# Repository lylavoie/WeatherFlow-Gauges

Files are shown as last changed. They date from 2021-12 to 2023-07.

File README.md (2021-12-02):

# WeatherFlow-Gauges

Drive a set of analog gauges from the UDP broadcast reports from a WeatherFlow Tempest weather station, using an ESP32 microcontroller.  Current gauges are for Wind Speed (MPH), Wind Direction (cardinal heading), and Temperature (degrees F).  The wind direction assumes there will be 8 LEDs, driven from an SPI output register.

The design is based the [TinyPICO](https://www.tinypico.com/) board.
Analog outputs are created from PWM output, combined with a low pass
filter.  Eight LEDs are driven from through an MCP23008 GPIO chip.  Two
additional LED (or general purpose digital outputs) are also provided
by GPIO pins on the TinyPICO. along with two digial inputs (buttons).

Power connections are J1, providing 5 to 12 volts DC, or through the
USB connection on the TinyPICO.

## PCB Design

The ``pcb/pdf`` directory provides the schematics and design layout of
the board.  The ``pcb/gerbers`` directory contains the production files
to spin the PCB board.

## Firmware

The firmware (this repo) is built via [PlatformIO](https://platformio.org/)
and VS Code.  Programming can be via the USB interfaces over over
the air, by selecting the built enviroment *tinypico_ota*.

## Operation & Setup

Settings are stored persistenly in the ESP32 EEPROM.  If the system
does not have a valid configuration, it will enable AP mode,
broadcasting the open (no encryption or passkey) SSID
*WeatherFlowGauges*.  After connecting to the system, the system
can be configured through a web broswer via
[http://192.168.4.1](http://192.168.4.1).  The initial username and
password is *admin*/*temp*.

System status is provided through the RBG LED on the TinyPICO board.

| LED Color | Meaning
| --- | ---
| Solid Blue | Trying to connect to Wi-Fi
| Pulsing Green | System connected to Wi-Fi, normal operation
| Color Wheel Cycle | Running as Wi-Fi AP, waiting for setup
| Solid Orange | Factory reset started
| Solid Red | Factory reset completed

### Factory Reset

While holding down **Button 1**, press the **Reset** button.  The
RBD LED will turn orange, keep holding Button 1 for at least 5
seconds until the RGB LED turns red, then release. The system has
now been reset back to the factory default settings.

## Gauages

TBD

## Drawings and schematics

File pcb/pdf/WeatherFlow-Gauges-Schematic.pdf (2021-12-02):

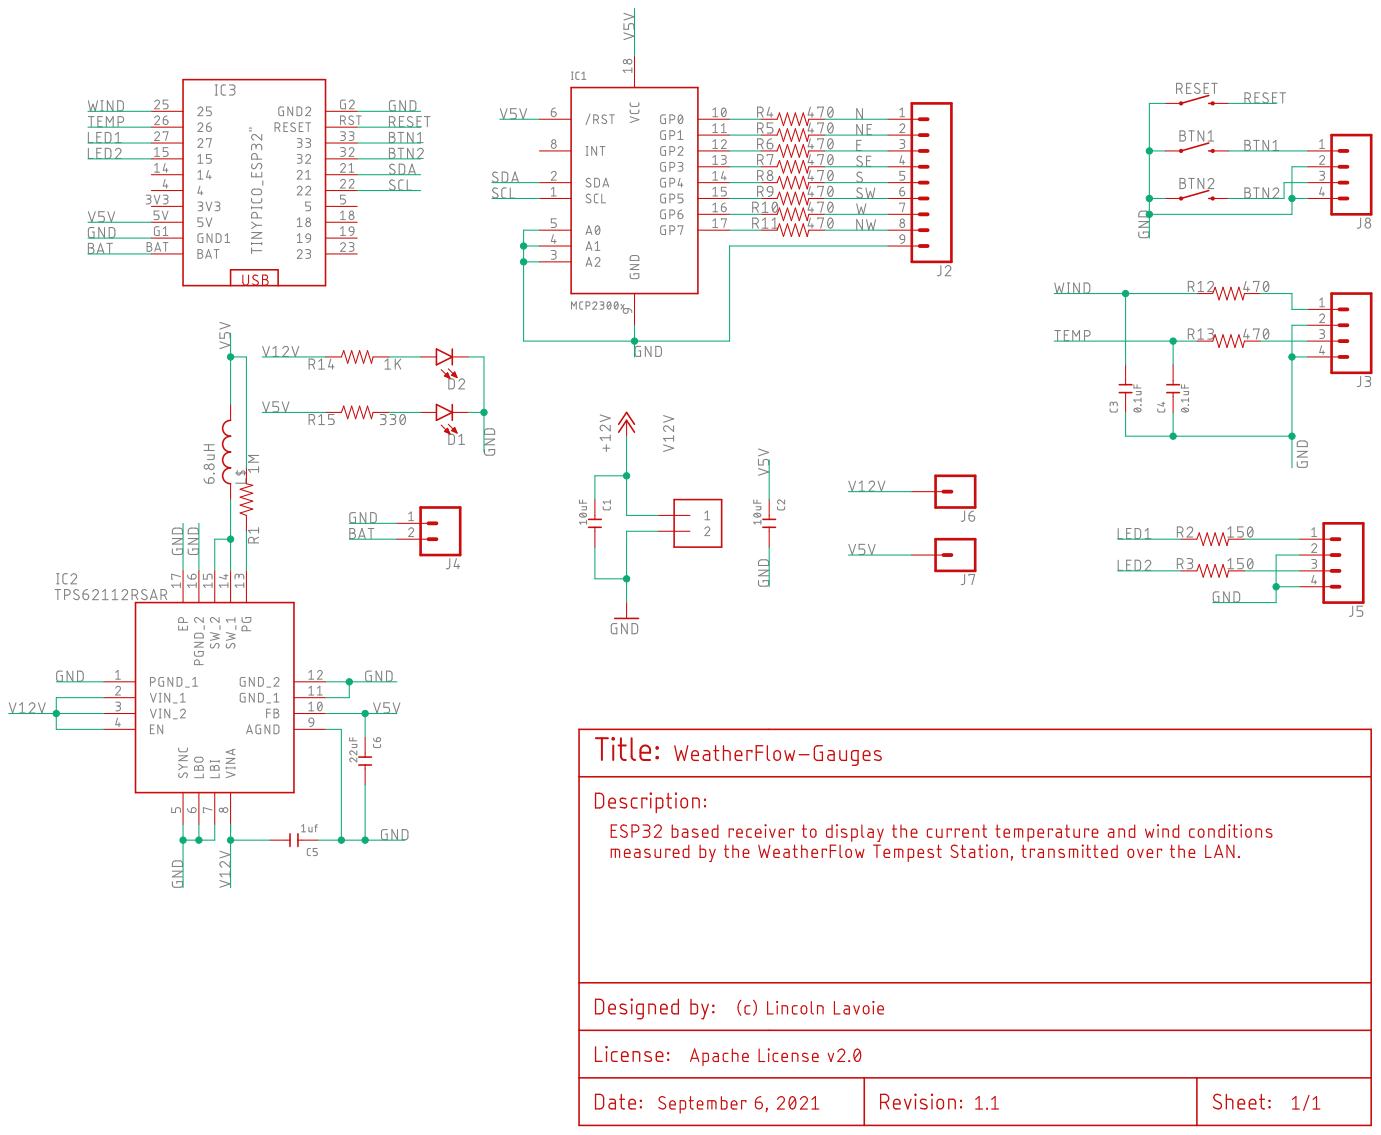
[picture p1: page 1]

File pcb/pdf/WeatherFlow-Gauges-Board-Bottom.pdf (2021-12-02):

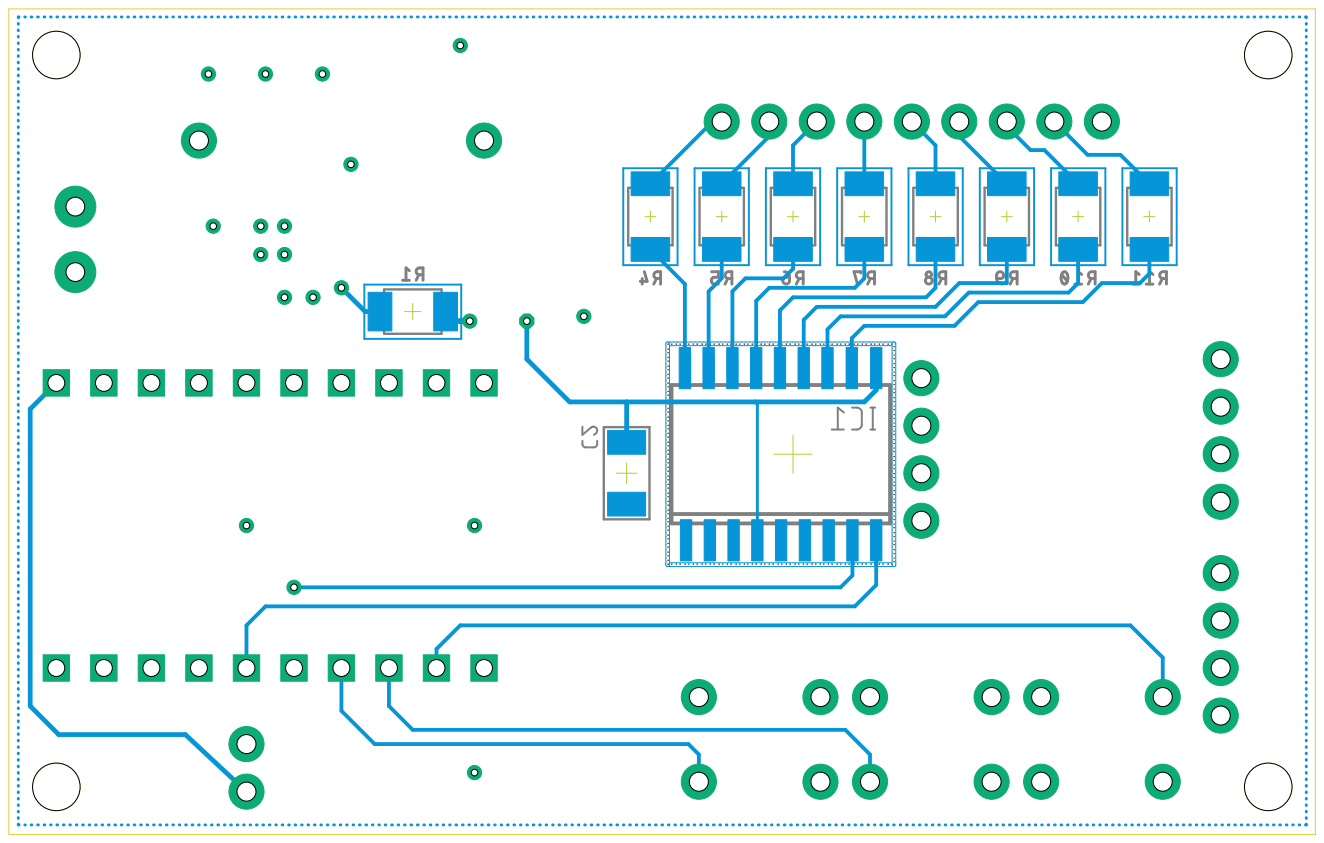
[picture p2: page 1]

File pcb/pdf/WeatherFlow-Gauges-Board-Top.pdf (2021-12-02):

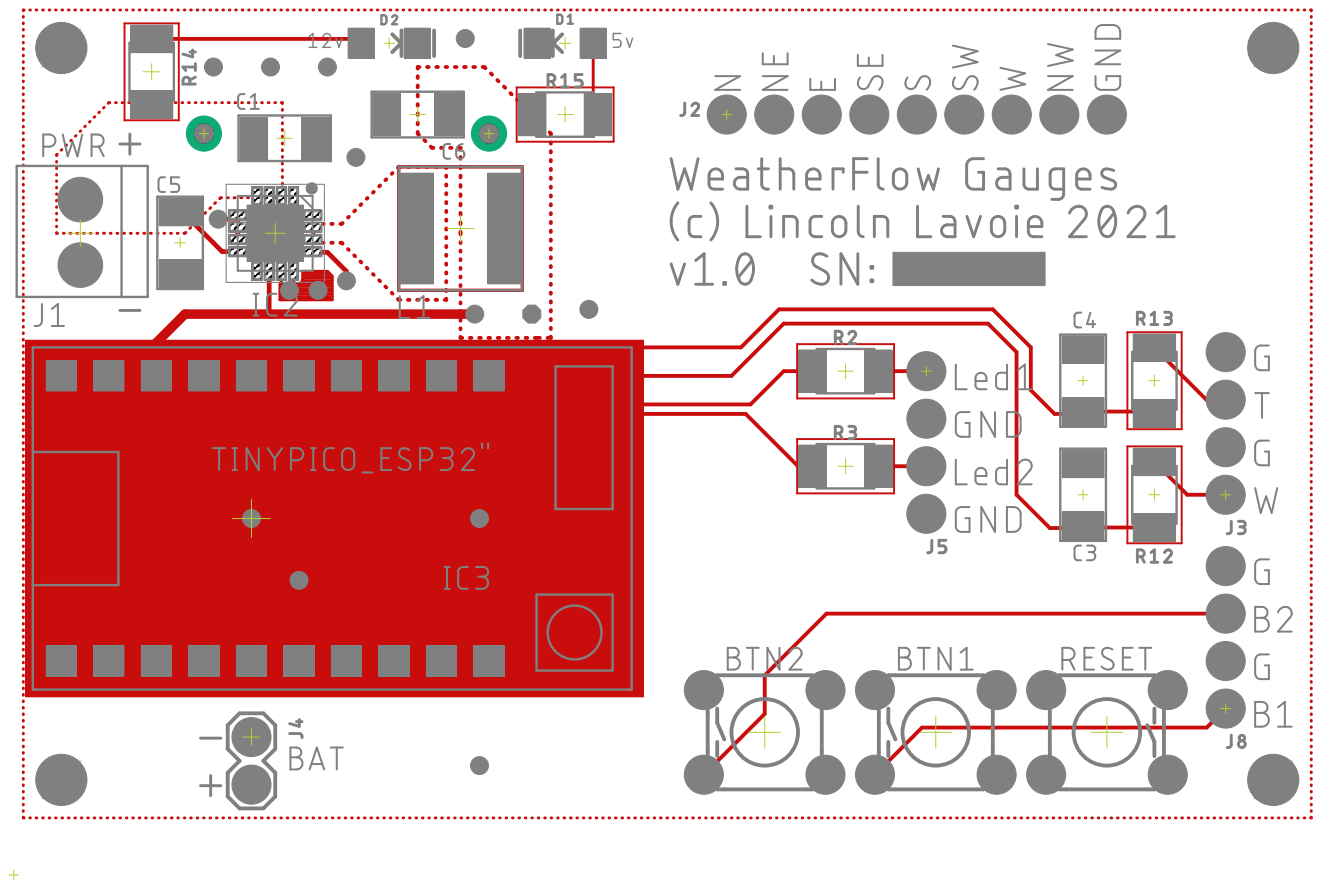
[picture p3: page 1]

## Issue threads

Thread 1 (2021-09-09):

Recover MCP23008 chip after resume from battery

lylavoie, 2021-09-09:
The MCP23008 chip is powered from the 5V supply, and when the TinyPICO power is restored, the chip needs to be reset / reinitialized.

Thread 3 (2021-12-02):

Power GPIO chip from 3V source

lylavoie, 2021-12-02:
Change PCB design to power the MCP23008 chip from the 3 volt source, which will allow it to run from the battery backup.

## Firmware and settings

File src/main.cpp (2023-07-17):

#include <Arduino.h>
#include <WiFi.h>
#include <AsyncTCP.h>
#include <ESPAsyncWebServer.h>
#include <ESPmDNS.h>
#include <ArduinoJson.h>
#include <TinyPICO.h>
#include <Adafruit_MCP23X08.h>
#include <SPIFFS.h>
#include <esp_task_wdt.h>
#include <wf.h>
#include <PersistSettings.h>
#include "Config.h"
#include <map>
#include <ctime>
#include <math.h>

// Note, these are required because of https://community.platformio.org/t/identifier-is-undefined-setenv-tzset/16162/2
//_VOID  _EXFUN(tzset,	(_VOID));
//int	_EXFUN(setenv,(const char *__string, const char *__value, int __overwrite));

// Version info
#define MAJOR 1
#define MINOR 3
#define PATCH 0

// Debug Info
#define DEBUG 2
void debug(int level, const char *fmt, ...);

// Hardware board
TinyPICO TP = TinyPICO();
// Output Guages
#define WINDGAUGEPIN 25
#define WINDCHANNEL 0
#define TEMPGAUGEPIN 26
#define TEMPCHANNEL 1
// Input/Output Settings
#define BTNPIN1 33
#define BTNPIN2 32
#define LED1 27
#define LED1CHANNEL 2
#define LED2 15
#define LED2CHANNEL 3

// WeatherFlow Handler
WeatherFlow WF(Imperial);

// Persistent Settings Handler
PersistSettings<AppConfig> Settings(AppConfig::Version);

// Hardware I2C GPIO extender
Adafruit_MCP23X08 mcp;

// Function Prototypes
void ledcAnalogWrite(uint8_t channel, uint32_t value, uint32_t valueMax = 8191);
uint32_t scalePwmOutput(double dataVal, double minScale, double maxScale, double halfScalePWM = 3600);
uint8_t encodeWind(int windDir);
void RunCalibration(void);


// WiFi Parameters
bool bSoftApActive = false;
#define AP_MODE_SSID "WeatherFlowGauges"

// Webserver and Websockets
AsyncWebServer objWebServer(80);
AsyncWebSocket objWebSocket("/ws");
void onWebSocketEvent(AsyncWebSocket *server, AsyncWebSocketClient *client, AwsEventType type,
  void *arg, uint8_t *data, size_t len);
void handleWebSocketMessage(AwsFrameInfo *info, uint8_t *data, size_t len);
String webTemplateProcessor(const String& var);
void webServerSpiffsHandler(AsyncWebServerRequest *request);

enum CalMode { none, range };
CalMode CalibrationMode = none;


// ##################################################################
// # Setup
// ##################################################################

void setup() {

  // ==================================================
  // Hardware Init Stuff
  // ==================================================
  SPIFFS.begin();

  // ==================================================
  // Setup the serial port for logging, if debugging
  // ==================================================
  #ifdef DEBUG
  Serial.begin(9600);
  while(!Serial)
  {
    Serial.print('.');
  }
  #endif
  
  // ==================================================
  // Settings (non-volitale)
  // ==================================================
  Settings.Begin();

  // ==================================================
  // Button Setup & Reset Default Settings
  // ==================================================
  pinMode(BTNPIN1, INPUT_PULLUP);
  int iSwitchDebounce = 0;
  while( !digitalRead(BTNPIN1) ){
    // Stage 0 reset, debouncing for 5 seconds
    TP.DotStar_SetPixelColor(0xFF9A00);
    TP.DotStar_SetBrightness(150);
    TP.DotStar_SetPower(true);
    // Stage 1 reset
    if( iSwitchDebounce++ > 10 ){
      TP.DotStar_SetPixelColor(0xFF0000);
      Settings.ResetToDefault();
      delay(5000);
      ESP.restart();
    }
    delay(500);
  }

  // ==================================================
  // Environment Startup
  // ==================================================
  setenv("TZ", Settings.Config.TimeZone, true);
  tzset();

  // ==================================================
  // Wi-Fi Startup
  // ==================================================
  if( !Settings.Config.WiFi.ssid[0] || !Settings.Config.WiFi.pass[0] ){
    // ------------------------------------
    // Soft AP mode
    // ------------------------------------
    debug(1, "\n\rWi-Fi parameters not set, starting AP mode.");
    
    // Start the AP mode
    debug(1, "\n\rStarting Wi-Fi AP for SSID: WeatherFlow");
    if( !WiFi.softAP(AP_MODE_SSID) ){
      debug(1, "\n\rFailed to start AP mode!");
      while(1);
    }

    bSoftApActive = true;
    TP.DotStar_SetBrightness(150); 
  }
  else{
    // ------------------------------------
    // STA mode
    // ------------------------------------
    debug(1, "\n\rConecting to Wi-Fi: %s ...", Settings.Config.WiFi.ssid);
    WiFi.begin(Settings.Config.WiFi.ssid, Settings.Config.WiFi.pass);
    int iWiFiFailCount = 0;
    TP.DotStar_SetPixelColor(0x0000FF);
    while(WiFi.status() != WL_CONNECTED)
    {
      debug(1, ".");
      delay(500);
      // Five some feedback via the DotStar
      if( iWiFiFailCount++ % 2 ){TP.DotStar_SetBrightness(150);}
      else{TP.DotStar_SetBrightness(25);}
      
    }

    debug(1, "\n\rWi-Fi connected!");
    TP.DotStar_SetPixelColor(0x00FF00);
    TP.DotStar_SetBrightness(25);
    #ifdef DEBUG
    char  chIP[81];
    WiFi.localIP().toString().toCharArray(chIP, sizeof(chIP) - 1);
    debug(1, "\n\rIP Address: %s", chIP);
    #endif
  }

  // ==================================================
  // IP Services
  // ==================================================

  // Setup mDNS
  if ( !MDNS.begin("wxgauges") ){debug(1, "Failed to start mDNS responder!");}

  // Setup the webserver and websocket handling
  // FIXME: Handle firmware update
  //objWebServer.on("/update", HTTP_POST, NULL);
  objWebServer.on("/logout", HTTP_GET, [](AsyncWebServerRequest *request){request->send(401);});
  objWebServer.on("/logged-out.html", HTTP_GET, webServerSpiffsHandler);
  objWebServer.onNotFound([](AsyncWebServerRequest *request){
    if( !request->authenticate(Settings.Config.Web.user, Settings.Config.Web.pass) )
      return request->requestAuthentication();
    webServerSpiffsHandler(request);
  });
  objWebSocket.onEvent(onWebSocketEvent);
  objWebServer.addHandler(&objWebSocket);
  objWebServer.begin();


  // ==================================================
  // PWM controls for gauge outputs
  // ==================================================
  
  // Wind PWM freq 5 kHz, 13-bit timer resolution
  ledcSetup(WINDCHANNEL, 5000, 13);
  ledcAttachPin(WINDGAUGEPIN, WINDCHANNEL);

  // Temp PWM freq 5 kHz, 13-bit timer resolution
  ledcSetup(TEMPCHANNEL, 5000, 13);
  ledcAttachPin(TEMPGAUGEPIN, TEMPCHANNEL);

  // LED PWM Setup, 5 kHz, 13-bit timer
  ledcSetup(LED1CHANNEL, 5000, 13);
  ledcAttachPin(LED1, LED1CHANNEL);
  ledcAnalogWrite(LED1CHANNEL, 0);
  ledcSetup(LED2CHANNEL, 5000, 13);
  ledcAttachPin(LED2, LED2CHANNEL);
  ledcAnalogWrite(LED2CHANNEL, 0);

  // ==================================================
  // Setup MCP23008 I2C GPIO Expander
  // ==================================================
  if (!mcp.begin_I2C()) {debug(1, "\n\rFailed to startup MCP23008!");}
  for(int i=0; i<8; i++)mcp.pinMode(i, OUTPUT);

  // ==================================================
  // Start listening for UDP messages
  // ==================================================
  if( !WF.Begin() )debug(1, "\n\rFailed to start WeatherFlow listener!");

  // ==================================================
  // Enable the watchdog timer
  // ==================================================
  esp_task_wdt_init(10, false);
  esp_task_wdt_add(NULL);
}

// ##################################################################
// # Main Loop
// ##################################################################

void loop() {
  static uint32_t u32WindPwm;
  static uint32_t u32TempPwm;
  static uint8_t u8WindDir;
  time_t ul32CurTime;
  static time_t ul32LastBlink;
  static bool bOneShot = false;
  static bool bGaugeLamp = false;


  // ================================================================
  // Watchdog timer reset & current time
  // ================================================================   
  time(&ul32CurTime);
  esp_task_wdt_reset();


  // ================================================================
  // Calibration modes
  // ================================================================
  if( CalibrationMode == range){
    debug(1, "\n\rRunning in calibration mode, current epoch time: %d", ul32CurTime);
    RunCalibration();
    delay(5000);
    return;
  }
  
  if( bSoftApActive ){
    // ================================================================
    // Wi-Fi in AP mode, allowing for user setup...
    // ================================================================
    // Cycle the DotStar color, just to give the user some feedback
    TP.DotStar_CycleColor(25);
  }
  else{
    // ================================================================
    // Wi-Fi in client mode, listening for WeatherFlow messages
    // ================================================================

    // Status via DotStar LED
    if( ul32CurTime%15 == 0 && !bOneShot ){
      bOneShot = true;
      TP.DotStar_SetPixelColor(0x00FF00);
      ul32LastBlink = ul32CurTime;
      // Log the current time
      char buf[128];
      strftime(buf, 128, "%c", localtime(&ul32CurTime));
      debug(1, "\n\rCurrent System Time: %s", buf); 
      debug(1, "\r\nFirmware Version: %d.%d.%d", MAJOR, MINOR, PATCH);
    }
    if( ul32CurTime - ul32LastBlink >= 1 ){
      bOneShot = false;
      TP.DotStar_SetPixelColor(0x0);
    }

    // ================================================================
    // WeatherFlow receiver loop function call, return indicates
    // new data is available
    // ================================================================
    if( WF.ReceiveLoop() ){
      debug(1, "\n\rReceived updated weather info...");
      
      // Check for Wind data
      if( WF.RapidWind().Valid() ){
        debug(1, "\n\rValid Rapid Wind data:");
        debug(1, "\n\r\tWind Speed: %f", WF.RapidWind().WindSpeed());
        debug(1, "\n\r\tWind Direction: %d", WF.RapidWind().WindDirection());

        u32WindPwm = scalePwmOutput(WF.RapidWind().WindSpeed(), Settings.Config.Wind.min,
          Settings.Config.Wind.max, Settings.Config.Wind.gain);
        debug(2, "\n\r\tWind PWM: %i", u32WindPwm);
        ledcAnalogWrite(WINDCHANNEL, u32WindPwm);

        if( WF.RapidWind().WindSpeed() >= Settings.Config.Wind.threshold ){ 
          u8WindDir = encodeWind(WF.RapidWind().WindDirection()); 
        }
        else{ 
          u8WindDir = 0x00;
        }
        debug(2, "\n\r\tWind direction code: 0x%02X", u8WindDir);
        mcp.writeGPIO(u8WindDir, 0);

        // Check if we need to update our system time
        if( abs(time(NULL) - WF.RapidWind().EpochTime()) > 10 ){
          debug(1, "\n\r\tUpdating the system time...");
          timeval WFtime;
          WFtime.tv_sec = WF.RapidWind().EpochTime();
          WFtime.tv_usec = 0;
          settimeofday(&WFtime, NULL);
          debug(2, "\n\r\t\tWF Epoch Time: %d", WF.RapidWind().EpochTime());
          debug(2, "\n\r\t\tSystem Time:   %d", time(NULL));
        }
      }

      // Check for valid Station data
      if( WF.ObservationTempest().Valid() ){
        debug(1, "\n\rValid Station Observation data:");
        debug(1, "\n\r\tAir Temperature: %f", WF.ObservationTempest().AirTemperature());
        u32TempPwm = scalePwmOutput(WF.ObservationTempest().AirTemperature(), Settings.Config.Temp.min,
          Settings.Config.Temp.max, Settings.Config.Temp.gain);
        debug(2, "\n\r\tTemp PWM: %i", u32TempPwm);
        ledcAnalogWrite(TEMPCHANNEL, u32TempPwm);
      }
    }
  
    // ================================================================
    // Check our current time, turn on the gauge lamps if needed
    // ================================================================
    tm *tmCurrentTime;
    tmCurrentTime = localtime(&ul32CurTime);
    if( !bGaugeLamp && tmCurrentTime->tm_hour == Settings.Config.GaugeLamps.OnHour 
        && tmCurrentTime->tm_min == Settings.Config.GaugeLamps.OnMinute ){
      bGaugeLamp = true;
      ledcAnalogWrite(LED1CHANNEL, scalePwmOutput(Settings.Config.GaugeLamps.LampBrightness, 0, 100, 4096));
    }
    if( bGaugeLamp && tmCurrentTime->tm_hour == Settings.Config.GaugeLamps.OffHour && 
        tmCurrentTime->tm_min == Settings.Config.GaugeLamps.OffMinute ){
      bGaugeLamp = false;
      ledcAnalogWrite(LED1CHANNEL, 0);
    }
  }

}

// ##################################################################
// # Debug printer
// #
// # Debug logging to the serial port, message is only printed if 
// # the level is >= to DEBUG (i.e. debugging level).  If DEBUG is
// # undefined, code is deactivated.
// ##################################################################
void debug(int level, const char *fmt, ...){
  #ifdef DEBUG
  if( level <= DEBUG ){
    char chBuffer[256];
    va_list args;
    va_start(args,fmt);
    vsprintf(chBuffer, fmt, args);
    va_end(args);
    Serial.print(chBuffer);
  }
  #endif
}

// ####################################################################
// # Run Calibration
// #
// # Runs a simple calibration, steping through the gauge "steps",
// # on each call (i.e. once per loop).  This allows the gain values
// # to easily be "tuned."
// ####################################################################
void RunCalibration(void){
  static float fWindSpeed = 0;
  static float fAirTemp = 0;
  static int iWindDirectionDegrees = 0;
  uint32_t u32WindPwm;
  uint32_t u32TempPwm;
  uint8_t u8WindDir;

  u32WindPwm = scalePwmOutput((double)fWindSpeed, Settings.Config.Wind.min, 
    Settings.Config.Wind.max, (double)Settings.Config.Wind.gain);
  debug(1, "\n\rWind PWM: %i", u32WindPwm);
  ledcAnalogWrite(WINDCHANNEL, u32WindPwm);

  fWindSpeed += Settings.Config.Wind.step;
  if( fWindSpeed > Settings.Config.Wind.max )fWindSpeed = Settings.Config.Wind.min;

  u32TempPwm = scalePwmOutput((double)fAirTemp, Settings.Config.Temp.min, 
    Settings.Config.Temp.max, (double)Settings.Config.Temp.gain);
  debug(1, "\n\rTemp PWM: %i", u32TempPwm);
  ledcAnalogWrite(TEMPCHANNEL, u32TempPwm);
  
  fAirTemp += Settings.Config.Temp.step;
  if( fAirTemp > Settings.Config.Temp.max )fAirTemp = Settings.Config.Temp.min;

  iWindDirectionDegrees+= 15;
  if( iWindDirectionDegrees > 360 )iWindDirectionDegrees = 0;
  u8WindDir = encodeWind(iWindDirectionDegrees);
  debug(1, "\n\rWind direction code: 0x%02X", u8WindDir);
  mcp.writeGPIO(u8WindDir, 0);
}


// ##################################################################
// # PWM and Wind LED outputs
// ##################################################################

// Analog PMW control, similar to Arduino analogWrite
void ledcAnalogWrite(uint8_t channel, uint32_t value, uint32_t valueMax) {
  // Write duty to LEDC, preventing writing above the max value
  ledcWrite(channel, min(value, valueMax));
}

// Scale our guage values, as needed
uint32_t scalePwmOutput(double dataVal, double minScale, double maxScale, double halfScalePWM){
  //double dRange = maxScale - minScale;
  //double dScaler = 1 / dRange;
  uint32_t u32Output = (uint32_t)floor(((dataVal - minScale) * halfScalePWM * (double)2) / (maxScale - minScale));
  return min(u32Output, (uint32_t)8192);
}

// Encode wind direction to the output for the LED driver.
// Assumes 8 LEDs, connected to 8-bit register
uint8_t encodeWind(int windDir){
  uint8_t u8WindDir;

  if( windDir >= (int)348.75 || windDir < (int)11.25 ){ u8WindDir = 0x01; debug(3,"\n\rWind Dir: N"); }         // N
  else if( windDir >= (int)11.25 && windDir < (int)33.75 ){ u8WindDir = 0x03; debug(3,"\n\rWind Dir: NNE"); }   // NNE
  else if( windDir >= (int)33.75 && windDir < (int)56.25 ){ u8WindDir = 0x02; debug(3,"\n\rWind Dir: NE"); }    // NE
  else if( windDir >= (int)56.25 && windDir < (int)78.75 ){ u8WindDir = 0x06; debug(3,"\n\rWind Dir: ENE"); }   // ENE
  else if( windDir >= (int)78.75 && windDir < (int)101.25 ){ u8WindDir = 0x04; debug(3,"\n\rWind Dir: E"); }    // E
  else if( windDir >= (int)101.25 && windDir < (int)123.75 ){ u8WindDir = 0x0C; debug(3,"\n\rWind Dir: ESE"); } // ESE
  else if( windDir >= (int)123.75 && windDir < (int)146.25 ){ u8WindDir = 0x08; debug(3,"\n\rWind Dir: SE"); }  // SE
  else if( windDir >= (int)146.25 && windDir < (int)168.75 ){ u8WindDir = 0x18; debug(3,"\n\rWind Dir: SSE"); } // SSE
  else if( windDir >= (int)168.75 && windDir < (int)191.25 ){ u8WindDir = 0x10; debug(3,"\n\rWind Dir: S"); }   // S
  else if( windDir >= (int)191.25 && windDir < (int)213.75 ){ u8WindDir = 0x30; debug(3,"\n\rWind Dir: SSW"); } // SSW
  else if( windDir >= (int)213.75 && windDir < (int)236.25 ){ u8WindDir = 0x20; debug(3,"\n\rWind Dir: SW"); }  // SW
  else if( windDir >= (int)236.25 && windDir < (int)258.75 ){ u8WindDir = 0x60; debug(3,"\n\rWind Dir: WSW"); } // WSW
  else if( windDir >= (int)258.75 && windDir < (int)281.25 ){ u8WindDir = 0x40; debug(3,"\n\rWind Dir: W"); }   // W
  else if( windDir >= (int)281.25 && windDir < (int)303.75 ){ u8WindDir = 0xC0; debug(3,"\n\rWind Dir: WNW"); } // WNW
  else if( windDir >= (int)303.75 && windDir < (int)326.25 ){ u8WindDir = 0x80; debug(3,"\n\rWind Dir: NW"); }  // NW
  else{ u8WindDir = 0x81; debug(3,"\n\rWind Dir: NNW"); }                                                       // NNW

  return u8WindDir;
}

// ##################################################################
// # Web Services (http server and websockets)
// ##################################################################

void notFound(AsyncWebServerRequest *request){
    request->send(404, "text/plain", "Not found");
}

void webServerSpiffsHandler(AsyncWebServerRequest *request){
  String path = request->url();
  String contentType;
  debug(2, "handleFileRead: %s", path);
  if (path.endsWith("/")) path += "index.html"; // Deal with the roots
  if (path.endsWith(".html")) contentType = "text/html";
  else if (path.endsWith(".css")) contentType = "text/css";
  else if (path.endsWith(".js")) contentType = "application/javascript";
  else if (path.endsWith(".ico")) contentType = "image/x-icon";
  else contentType = "text/plain";
  if( SPIFFS.exists(path) ){ 
    request->send(SPIFFS, path, contentType, false, webTemplateProcessor); 
  }
  else{ 
    request->send(404, "text/plain", "Not Found");
  }
}

void onWebSocketEvent(AsyncWebSocket *server, AsyncWebSocketClient *client, AwsEventType type,
    void *arg, uint8_t *data, size_t len){
  switch (type) {
  #ifdef DEBUG
    case WS_EVT_CONNECT:
      debug(1, "\r\nWebsocket connected (ClientID: %u, ClientIP:  %s)", client->id(), client->remoteIP().toString());
      break;
    case WS_EVT_DISCONNECT:
      debug(1, "\r\nWebscoked disconnected (ClientID: %u", client->id());
      break;
    case WS_EVT_PONG:
    case WS_EVT_ERROR:
      break;
  #endif
    case WS_EVT_DATA:
      handleWebSocketMessage( (AwsFrameInfo*) arg, data, len);
      break;
  }    
  return;
  }

void handleWebSocketMessage(AwsFrameInfo *info, uint8_t *data, size_t len){
  // Make sure this is a complete message and the is "text".
  if (info->final && info->index == 0 && info->len == len && info->opcode == WS_TEXT) {
    data[len] = 0;  // C-STR terminator
    debug(2, "\r\nRaw websocket payload: %s", (char*)data);
    DynamicJsonDocument jsonWsMsg(1000);
    if( deserializeJson(jsonWsMsg, (char*)data) == DeserializationError::Ok){
      // We've got a valid message folks
      const char *chMsgtype = jsonWsMsg["type"];
      const std::map<std::string,int> mapWsMsgTypes { {"updateSettings", 1}, {"updateWiFi", 2}, {"updateUser", 3} };
      switch( mapWsMsgTypes.find(std::string(chMsgtype))->second ){
        // Update System Settings
        case 1:{
            
            Settings.Config.Wind.min = jsonWsMsg["payload"]["wind"]["min"];
            Settings.Config.Wind.max = jsonWsMsg["payload"]["wind"]["max"];
            Settings.Config.Wind.step = jsonWsMsg["payload"]["wind"]["step"];
            Settings.Config.Wind.gain = jsonWsMsg["payload"]["wind"]["gain"];
            Settings.Config.Wind.threshold = jsonWsMsg["payload"]["wind"]["threshold"];

            Settings.Config.Temp.min = jsonWsMsg["payload"]["temp"]["min"];
            Settings.Config.Temp.max = jsonWsMsg["payload"]["temp"]["max"];
            Settings.Config.Temp.step = jsonWsMsg["payload"]["temp"]["step"];
            Settings.Config.Temp.gain = jsonWsMsg["payload"]["temp"]["gain"];

            if( strcmp("range", jsonWsMsg["payload"]["cal"]["mode"]) == 0 ){
              CalibrationMode = range;
            }
            if( strcmp("none", jsonWsMsg["payload"]["cal"]["mode"]) == 0 ){
              CalibrationMode = none;
            }
          }
          break;

        // updateWiFi
        case 2:{
            strcpy(Settings.Config.WiFi.ssid, jsonWsMsg["payload"]["wifi"]["ssid"]);
            strcpy(Settings.Config.WiFi.pass, jsonWsMsg["payload"]["wifi"]["pw"]);
            Settings.Write();
            debug(1, "\n\rGot Wi-Fi parameters, SSID: %s, and password: %s", 
              Settings.Config.WiFi.ssid, Settings.Config.WiFi.pass);
            delay(2000);
            ESP.restart();
          }
          break;

        //updateUser
        case 3:{
            strcpy(Settings.Config.Web.user, jsonWsMsg["payload"]["auth"]["user"]);
            strcpy(Settings.Config.Web.pass, jsonWsMsg["payload"]["auth"]["pass"]);
            Settings.Write();
            debug(1, "\n\rGot Auth parameters, user: %s, and password: %s", 
              Settings.Config.Web.user, Settings.Config.Web.pass);
          }
          break;

        default:{
            debug(1, "\r\nUnknown websocket message type: %s", chMsgtype);
          }
          break;  
      }
    }
  }
}
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

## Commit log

2021-07-03 Initial commits
    * Core functionality is working, need to finalize hardware design,
    including SPI register for wind direction LEDs.
2021-08-09 Add PCB board files
    * Initial 1.0 spin of the PCB hardware.
    [WeatherFlow-Gauges.GBL, WeatherFlow-Gauges.GBO, WeatherFlow-Gauges.GBP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]
2021-12-02 Updated PCB production files.
    * All files as built for Rev. 1.0, except:
    ** J1 changed to correct footprint.
    [WeatherFlow-Gauges.GKO, copper_bottom.gbr, copper_top.gbr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]
2021-12-02 Working code
    * Settings available through AP mode.
    * Web interface created.
    * Calibration and settings available through web interface.
    * Wind direction indication through MCP23008 chip.
2022-04-20 Added watchdog time function. (#4)
    * Watchdog with reset interval of 10 seconds
    [main.cpp]
2022-04-20 Add weatherflow class (#5)
    * Full WeatherFlow Class (all message and device types)
    * Parses messages for RapidWind, RainStart, LightningStrike, and Tempest Station.
    * Supports units setting on construction.
    * Rough implementation in main code, need to clean up.
    * System time synced from RapidWind messages.
    * Support for Gauge Lamps on/off based on system time.
    * Updated calibration handling for WeatherFlow class
    * Removed fixed mode calibration.
    * Moved range calibration to function outside of loop().
    * Fixed checks on WiFi settings.
    * TODO: Add missing ConfigSettings, as noted in code.
    [main.cpp]
2022-04-26 Add persist settings (#6)
    * Added lylavoie/PersistSettings library to implements NFS storage of config object.
    * Moved all settings into Settings.Config (PersistSettings object).
    * Config definition, including defaults separated to dedicated header file.
    * Moved default values into Config.h header.
    * Added settings for gauge lamps and timezone.
    * Updated web UI to remove fixed mode calibration.
    * Fixed issue with watchdog timer when in calibration mode.
    * Removed TinypicoOTA environment
    [main.cpp]
2023-07-17 Fixes to gauge scaling (#8)
    * Fixes to gauge scaling
    * Change to use a half scale PWM value
    * Updated to the config for the new scaling method.
    * Fixed temp gauge and lights
    * Fixed the temp gauge calibration.
    * Fixed the LED PWM output.
    [main.cpp]
